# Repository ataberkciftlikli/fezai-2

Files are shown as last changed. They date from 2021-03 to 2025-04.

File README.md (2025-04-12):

# fezai-2
Halley'in Çırakları Rocket Team - Fezai II - Flight Computer - 2021

Main Flight Computer -> Teensy 3.5 Microcontroller
                     -> Adafruit Ultimate GPS
                     -> Xbee Pro S2C
                     -> BMP 280
                     -> MPU6050
                     -> LM2596-ADJ
                     -> IRF540

Second Flight Computer -> Teensy 3.5 Microcontroller
                       -> Adafruit Ultimate GPS
                       -> Xbee Pro S2C
                       -> BMP 180
                       -> MPU9050
                       -> LM2596-ADJ
                       -> IRF540

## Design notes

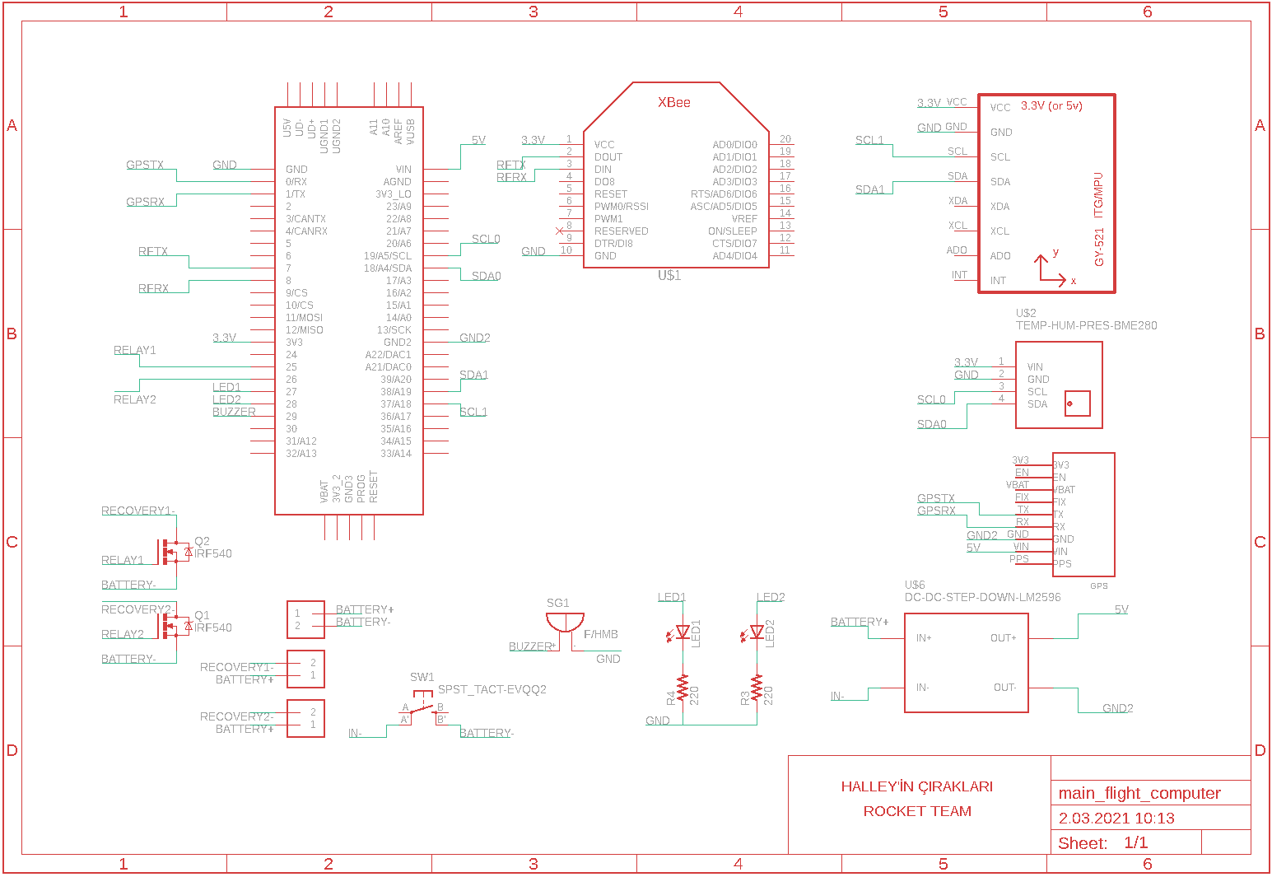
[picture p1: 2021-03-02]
Main Flight Computer/Schematic.png

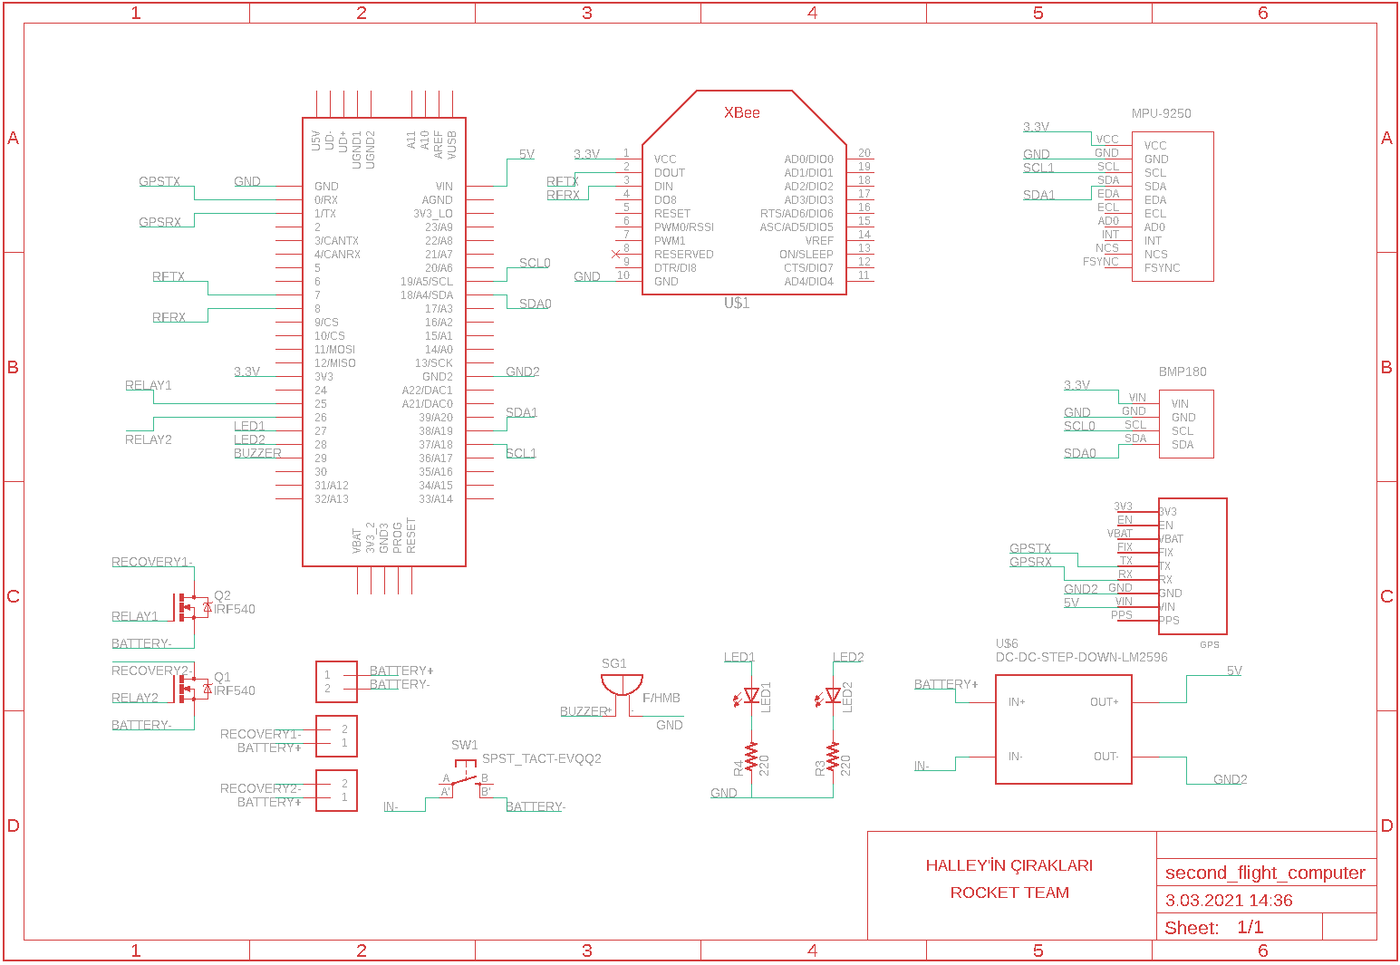
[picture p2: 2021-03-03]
Second Flight Computer/Schematic.png

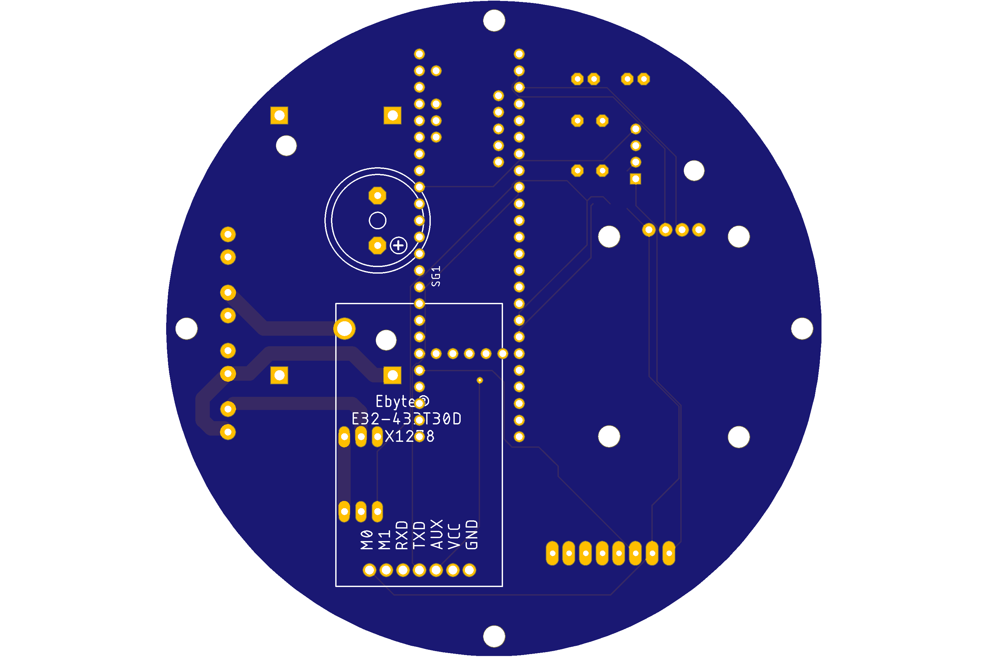
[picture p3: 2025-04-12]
Flight Computer v1.2/main_flight_computer_bottom.png

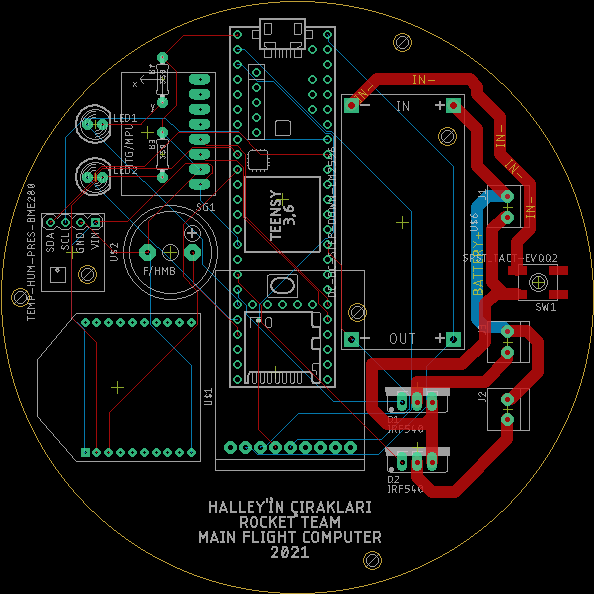
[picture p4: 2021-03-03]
Main Flight Computer/Board.png

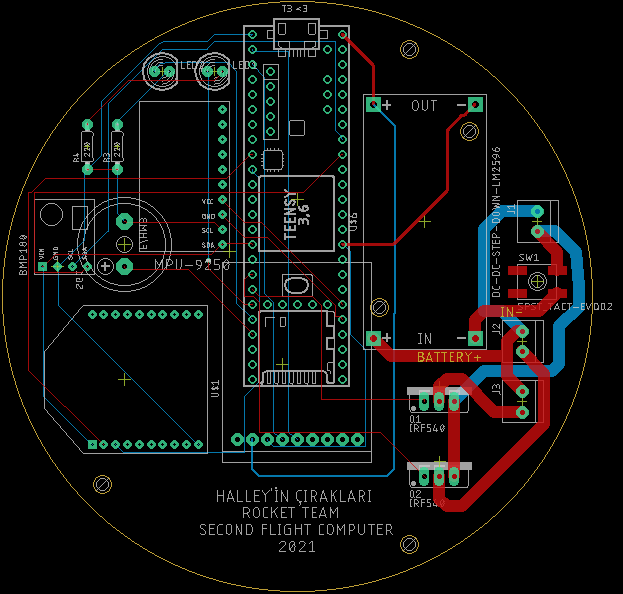
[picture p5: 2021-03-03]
Second Flight Computer/Board.png

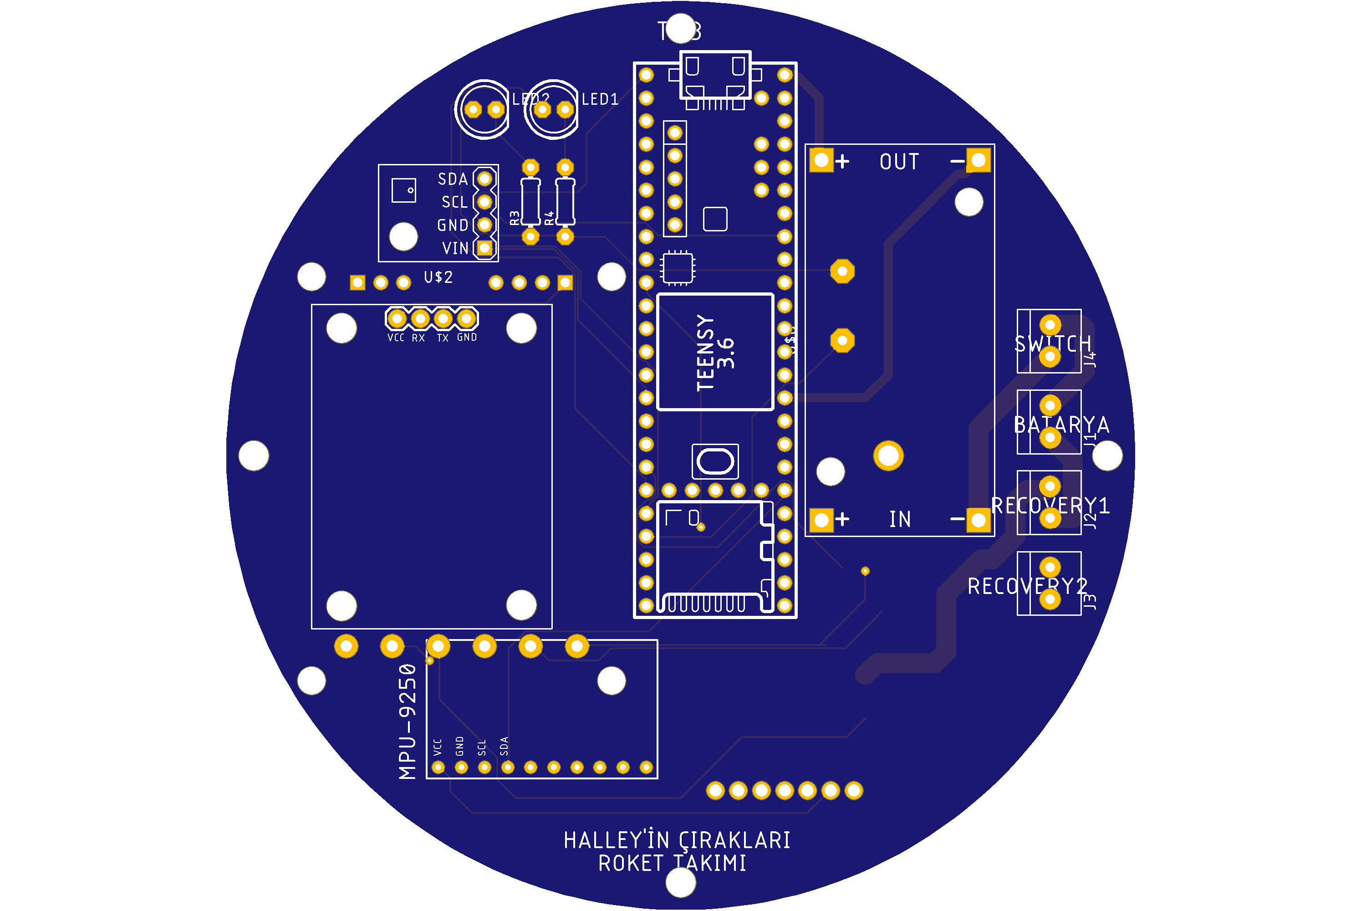
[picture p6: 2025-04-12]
Flight Computer v1.2/secondary_flight_computer_front.png

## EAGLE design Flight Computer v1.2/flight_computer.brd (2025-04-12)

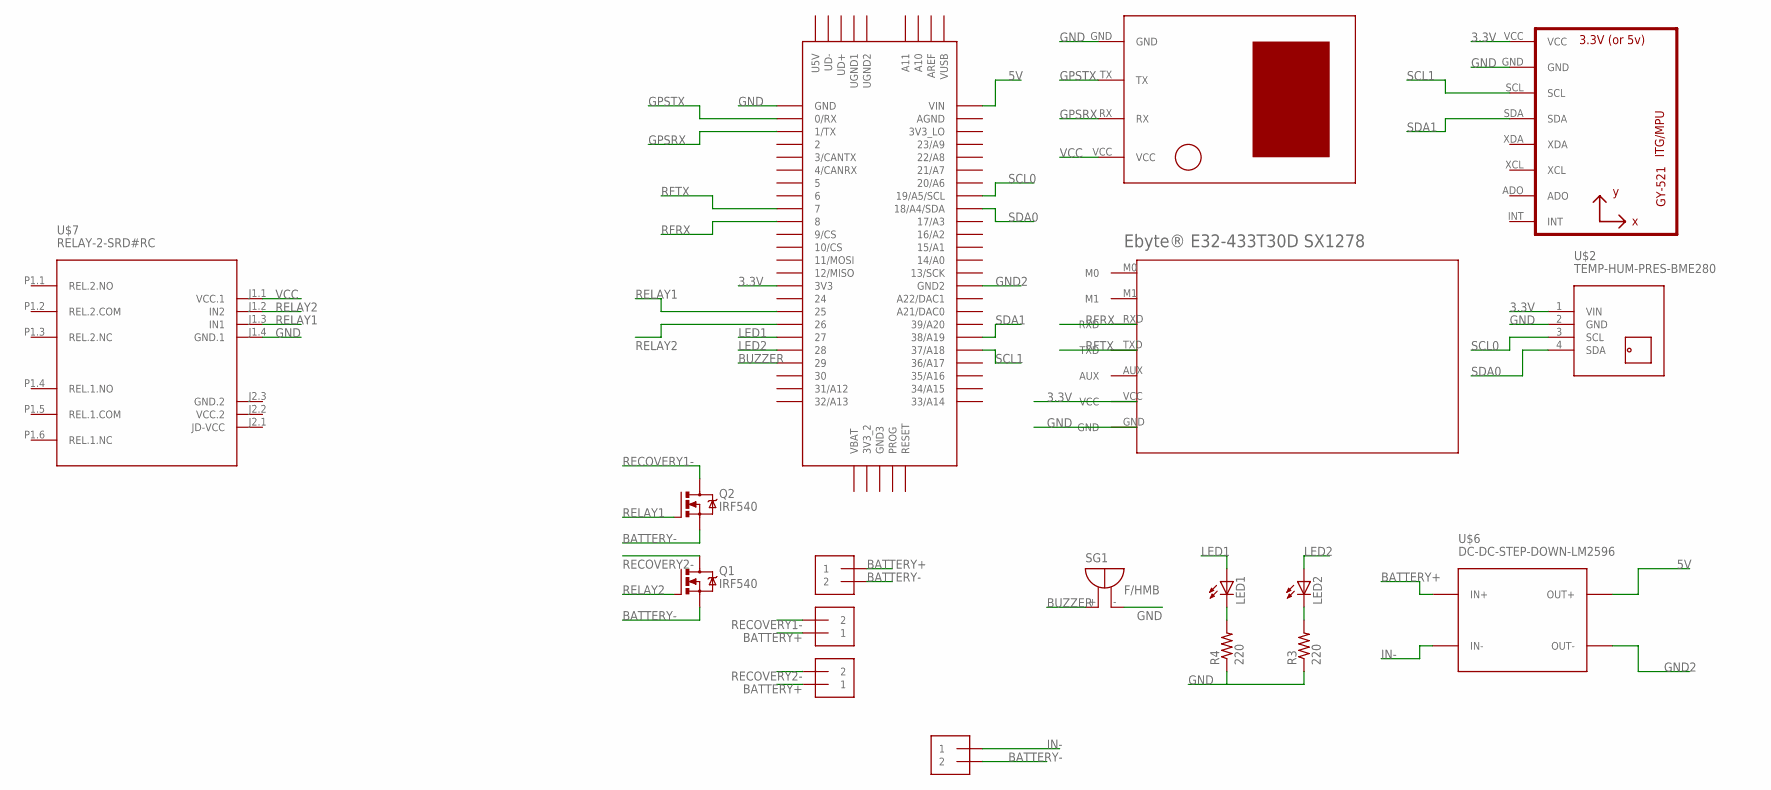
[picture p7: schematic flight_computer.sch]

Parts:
J1, J2, J3, J4: 1X2-3.5MM
LED1, LED2: LED5MM
Q1, Q2: IRF540; TO220BV
R3, R4: 220; 0204/7
SG1: F/HMB
U1: GY-521MPU6050; GY-521
U$1: U-BLOX-NEO6V2
U$2: TEMP-HUM-PRES-BME280
U$3: TEENSY_3.5/3.6
U$4: EBYTE®E32-433T30DSX1278; E32-433T30D
U$6: DC-DC-STEP-DOWN-LM2596
U$7: RELAY-2-SRD#RC

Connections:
3.3V: U1.VCC, U$2.1 (VIN), U$3.3V3, U$4.VCC
5V: U$3.VIN, U$6.OUT+
BATTERY+: J1.1, J2.1, J3.1, U$6.IN+
BATTERY-: J1.2, J4.2, Q1.S, Q2.S
BUZZER: SG1.+, U$3.29
GND: R3.1, R4.1, SG1.-, U1.GND, U$1.GND, U$2.2 (GND), U$3.GND, U$4.GND, U$7.J1.4 (GND.1)
GND2: U$3.GND2, U$6.OUT-
GND.2: U$7.J2.3 (GND.2)
GPSRX: U$1.RX, U$3.1/TX
GPSTX: U$1.TX, U$3.0/RX
IN-: J4.1, U$6.IN-
LED1: LED1.A, U$3.27
LED2: LED2.A, U$3.28
unnamed: LED1.K (C), R4.2
unnamed: LED2.K (C), R3.2
RECOVERY1-: J2.2, Q2.D
RECOVERY2-: J3.2, Q1.D
RELAY1: Q2.G, U$3.25, U$7.J1.3 (IN1)
RELAY2: Q1.G, U$3.26, U$7.J1.2 (IN2)
RFRX: U$3.8, U$4.RXD
RFTX: U$3.7, U$4.TXD
SCL0: U$2.3 (SCL), U$3.19/A5/SCL
SCL1: U1.SCL, U$3.37/A18
SDA0: U$2.4 (SDA), U$3.18/A4/SDA
SDA1: U1.SDA, U$3.38/A19
VCC: U$1.VCC, U$7.J1.1 (VCC.1)
VCC.2: U$7.J2.2 (VCC.2)

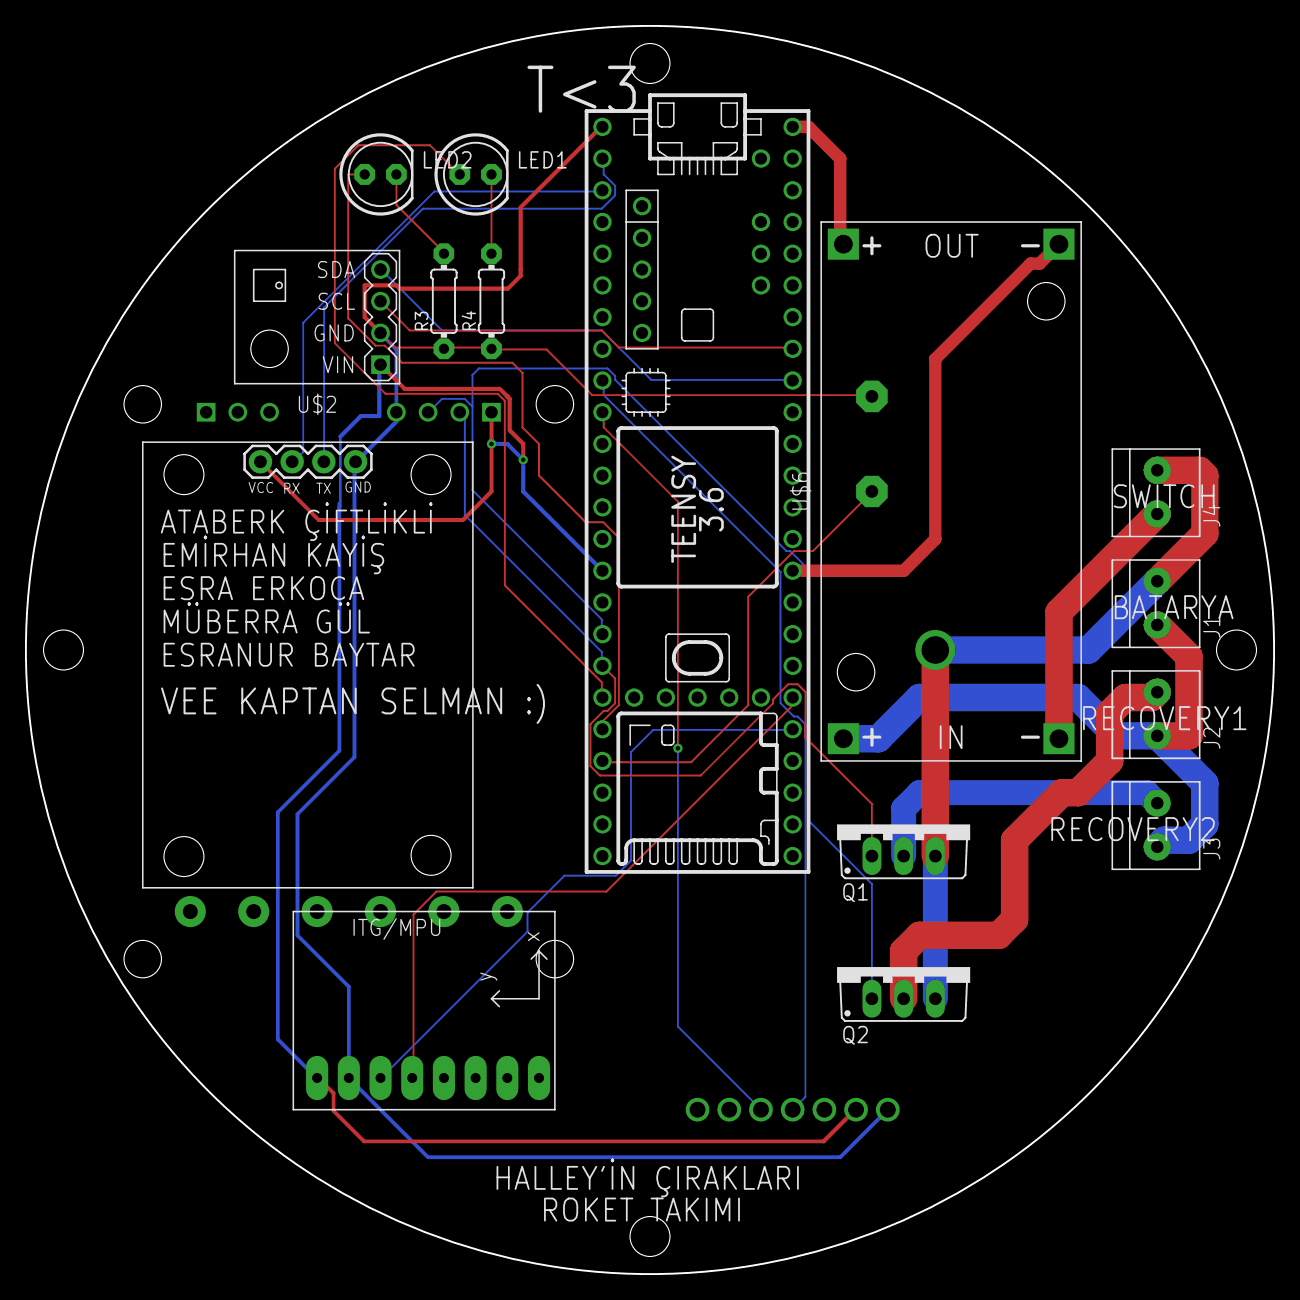
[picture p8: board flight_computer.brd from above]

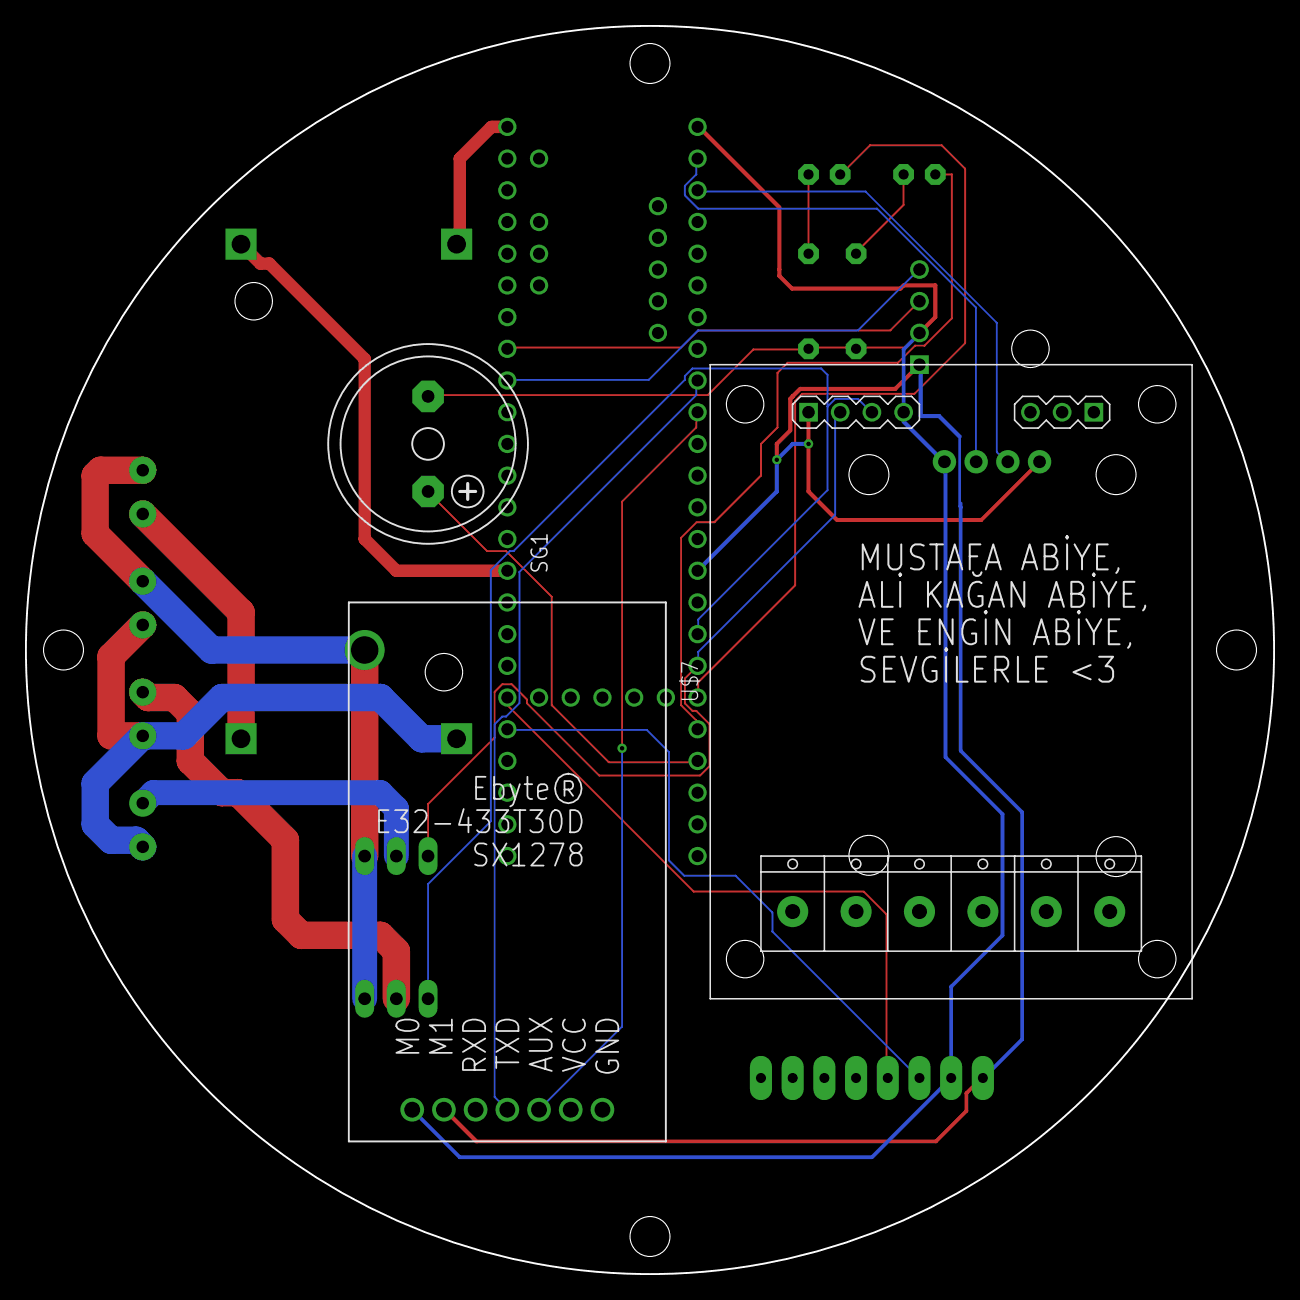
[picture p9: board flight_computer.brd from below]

Board: 2 copper layers, 100.0 x 100.0 mm, 18 parts (3 on the bottom side), 25 nets.

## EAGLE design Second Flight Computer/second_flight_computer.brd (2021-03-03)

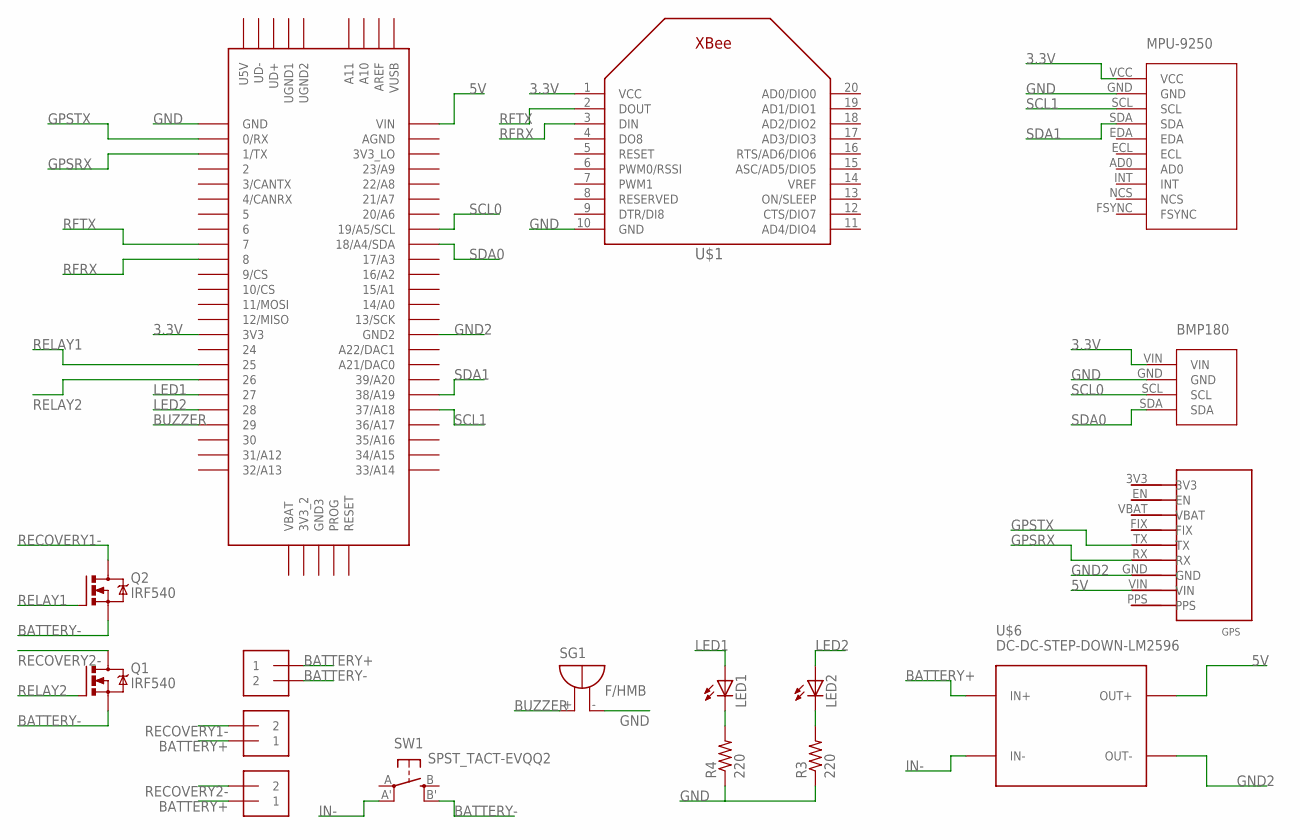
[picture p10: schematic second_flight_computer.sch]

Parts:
BMP1: BMP180
J1, J2, J3: 1X2-3.5MM
LED1, LED2: LED5MM
MPU-1: MPU-9250
Q1, Q2: IRF540; TO220BV
R3, R4: 220; 0204/7
SG1: F/HMB
SW1: SPST_TACT-EVQQ2; EVQ-Q2
U$1: XBEE
U$3: TEENSY_3.5/3.6
U$5: GPS
U$6: DC-DC-STEP-DOWN-LM2596

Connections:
3.3V: BMP1.VIN, MPU-1.VCC, U$1.1 (VCC), U$3.3V3
5V: U$3.VIN, U$5.VIN, U$6.OUT+
BATTERY+: J1.1, J2.1, J3.1, U$6.IN+
BATTERY-: J1.2, Q1.S, Q2.S, SW1.B' (S1)
BUZZER: SG1.+, U$3.29
GND: BMP1.GND, MPU-1.GND, R3.1, R4.1, SG1.-, U$1.10 (GND), U$3.GND
GND2: U$3.GND2, U$5.GND, U$6.OUT-
GPSRX: U$3.1/TX, U$5.RX
GPSTX: U$3.0/RX, U$5.TX
IN-: SW1.A' (P1), U$6.IN-
LED1: LED1.A, U$3.27
LED2: LED2.A, U$3.28
unnamed: LED1.K (C), R4.2
unnamed: LED2.K (C), R3.2
RECOVERY1-: J2.2, Q2.D
RECOVERY2-: J3.2, Q1.D
RELAY1: Q2.G, U$3.25
RELAY2: Q1.G, U$3.26
RFRX: U$1.3 (DIN), U$3.8
RFTX: U$1.2 (DOUT), U$3.7
SCL0: BMP1.SCL, U$3.19/A5/SCL
SCL1: MPU-1.SCL, U$3.37/A18
SDA0: BMP1.SDA, U$3.18/A4/SDA
SDA1: MPU-1.SDA, U$3.38/A19

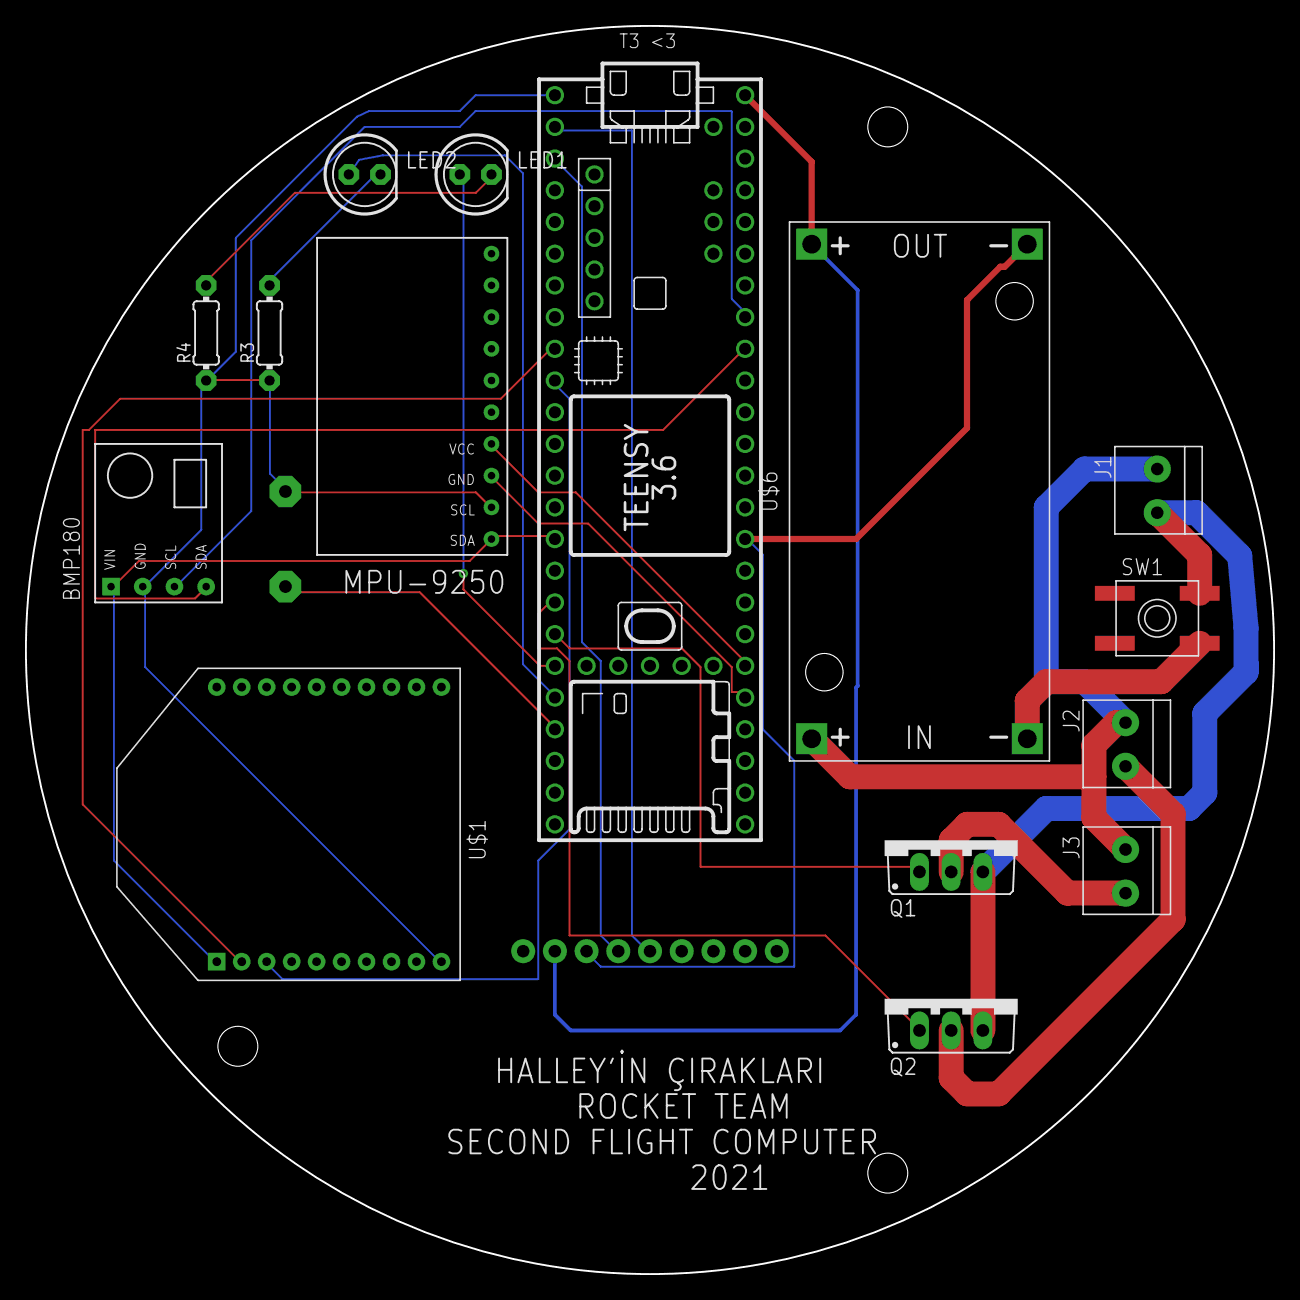
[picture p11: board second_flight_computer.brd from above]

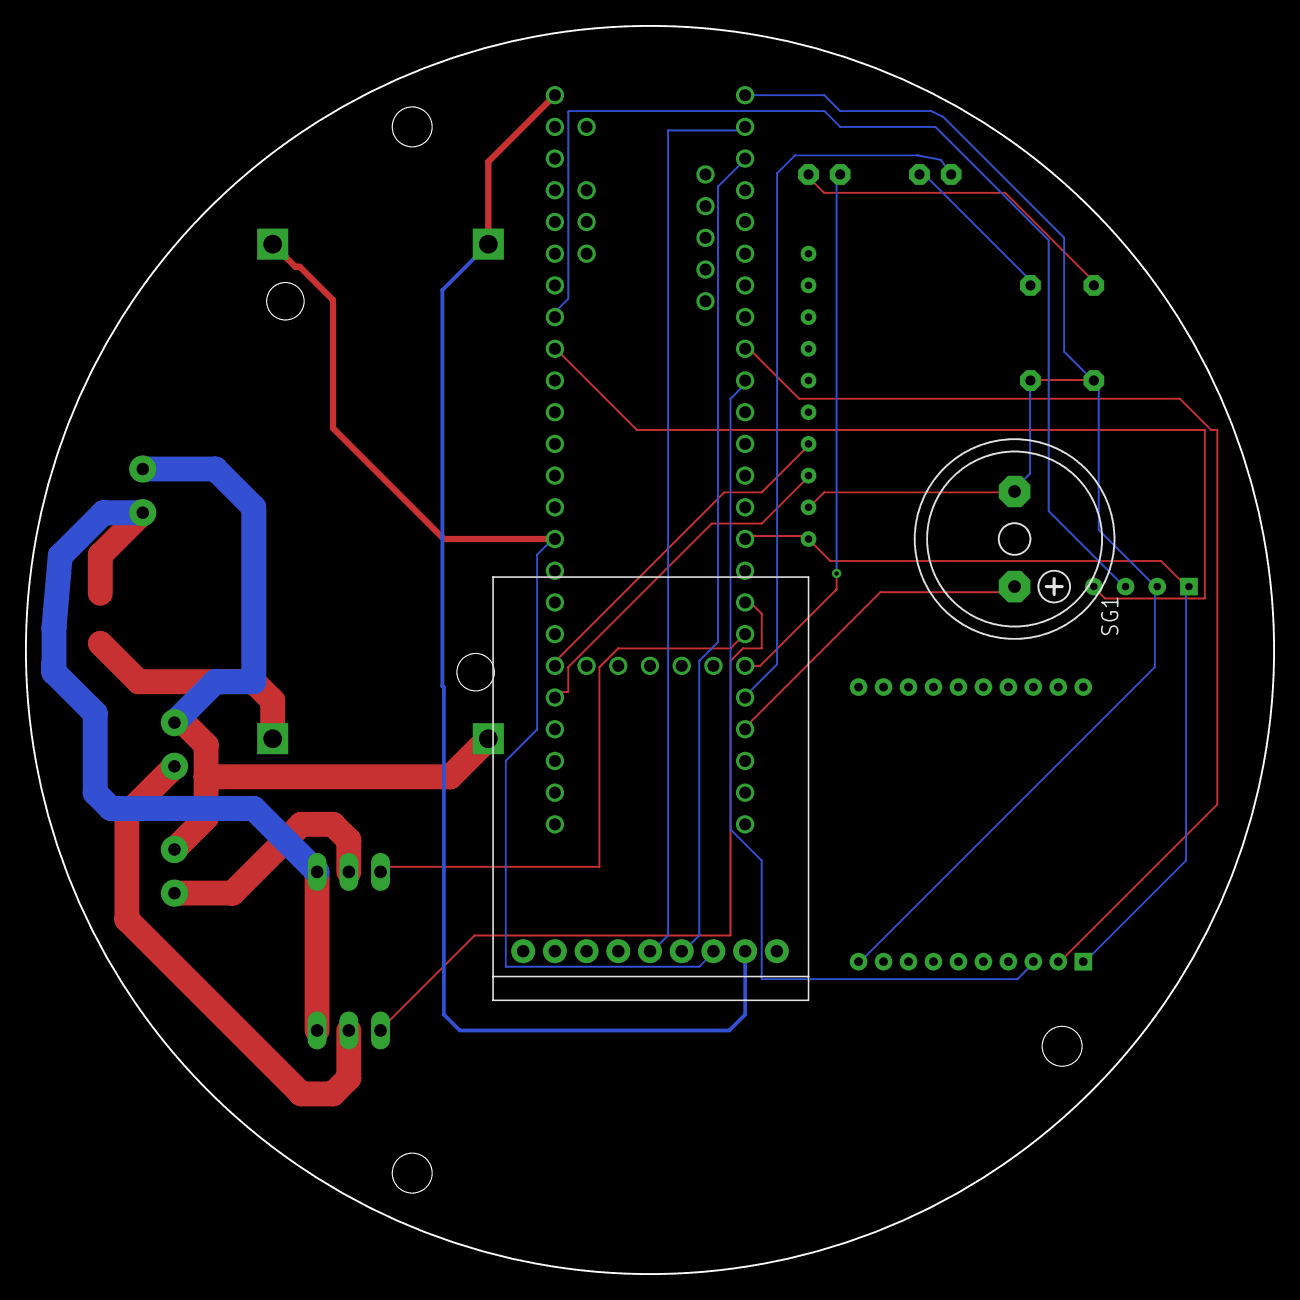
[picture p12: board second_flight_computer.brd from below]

Board: 2 copper layers, 100.0 x 100.0 mm, 17 parts (2 on the bottom side), 24 nets.

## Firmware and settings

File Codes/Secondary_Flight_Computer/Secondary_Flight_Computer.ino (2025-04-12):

#include <SoftwareSerial.h>
#include <Wire.h>
#include <SPI.h>
#include <SFE_BMP180.h> 
#include "MPU9250.h"

MPU9250 mpu;


SoftwareSerial GPS(0, 1); // RX, TX
SFE_BMP180 pressure;  // I2C BMP280

int led_green = 27; // Led 1  -> Green Status Led
int led_red = 28; // Led 2 -> Red Status Led
int buzzer = 29; // Buzzer
int relay_one = 25; // Recovery 1
int relay_two = 26; // Recovery 2

boolean apogee = false;
float altidute;
float altidute_old;
float velocity;

float security_altidute = 1; //DEĞİŞECEK!! STANDART 500
float altidute_secondary = 10; //DEĞİŞECEK!! STANDART 500
float last_altidute = 2; //DEĞİŞECEK!! STANDART 25

double baseline; // baseline pressure

int state = 0;
String state_string;
boolean system_state = false;

String gps_clock = "";    // hhmmss.00
String gps_latitude = "";   // DDMM.MMMM Kuzey/Güney N/S - Enlem
String gps_longitude = "";  // DDMM.MMMM Doğu/Batı E/W - Boylam
String gps_altidute = "";  // metre

void setup() {
  Serial.begin(9600);
  GPS.begin(9600);

  if (pressure.begin())
    Serial.println("BMP180 init success");
  else
  {
    // Oops, something went wrong, this is usually a connection problem,
    // see the comments at the top of this sketch for the proper connections.

    Serial.println("BMP180 init fail (disconnected?)\n\n");
    while(1); // Pause forever.
  }
  

  if (!mpu.setup(0x68)) {  // change to your own address
        while (1) {
            Serial.println("MPU connection failed. Please check your connection with `connection_check` example.");
            delay(5000);
        }
    }

    
   baseline = getPressure();
  
  Serial.print("baseline pressure: ");
  Serial.print(baseline);
  Serial.println(" mb");  


  pinMode(led_green,OUTPUT);
  pinMode(led_red,OUTPUT);
  pinMode(buzzer,OUTPUT);
  //pinMode(relay_one,OUTPUT);
  //pinMode(relay_two,OUTPUT);


  Serial.println("All sensors were calibrated successfully!");
  digitalWrite(led_green,HIGH);
  
  delay(100);
}

void loop() {

 
  altidute = pressure.altitude(getPressure(),baseline);
  mpu.update();

  if(altidute>=security_altidute && state==0) {
    state=1;
    digitalWrite(buzzer,HIGH);
    digitalWrite(led_green,LOW);
    digitalWrite(led_red,HIGH);
    delay(250);
    digitalWrite(buzzer,LOW);
    digitalWrite(led_green,HIGH);
    digitalWrite(led_red,LOW);
  }

  if (state==1 && mpu.getPitch()>35) {
    digitalWrite(relay_one,HIGH);
    digitalWrite(buzzer,HIGH);
    digitalWrite(led_green,LOW);
    digitalWrite(led_red,HIGH);
    delay(1200); //DİRENÇ TELİ SÜRESİ
    digitalWrite(relay_one,LOW);
    digitalWrite(buzzer,LOW);
    digitalWrite(led_green,HIGH);
    digitalWrite(led_red,LOW);
    apogee=true;
    state=2;
}

if(state==2 && altidute<=altidute_secondary) {
    digitalWrite(relay_two,HIGH);
    digitalWrite(buzzer,HIGH);
    digitalWrite(led_green,LOW);
    digitalWrite(led_red,HIGH);
    delay(2000); //LINEER SÜRESİ
    digitalWrite(relay_one,LOW);
    digitalWrite(buzzer,LOW);
    digitalWrite(led_green,HIGH);
    digitalWrite(led_red,LOW);
    state=3;
}

if(state==3 && altidute<=last_altidute && 0<=altidute_old-altidute<=1) {
    state=4;
}


  switch (state) {
  case 0:
    state_string="Yerde"; // Waiting for flight
    break;
  case 1:
    state_string="Uçuş"; // Flight started
    break;
  case 2:
    state_string="Tepe noktasına ulaşıldı! Faydalı yük bıraklıdı. İkinci Paraşüt açıldı."; // Apogee, Payload, Recovery 1 -> Secondary Parachute
    break;
  case 3:
    state_string="Ana paraşüt açıldı!"; // 500 meters, Recovery 2 -> Main Parachute
    break;
  case 4:
    state_string="İniş Tamamlandı!"; // Flight completed
    digitalWrite(led_green,LOW);
    digitalWrite(buzzer,HIGH);
    delay(800);
    digitalWrite(led_green,HIGH);
    digitalWrite(buzzer,LOW);
    delay(500);
    digitalWrite(buzzer,HIGH);
    break;
}
  
  ListenGPS();
  Serial.println("<------ VERİ ------>");
  //Serial.print("Saat:");
  //Serial.println(gps_clock);
  Serial.println("Enlem: 4099.7555");
  //Serial.println(gps_latitude);
  Serial.print("Boylam: 2906.4266");
  //Serial.print("GPS İrtifa:");
  //Serial.println(gps_altidute);
  Serial.println("");
  
    Serial.print("Yaw, Pitch, Roll: ");
    Serial.print(mpu.getYaw(), 2);
    Serial.print(", ");
    Serial.print(mpu.getPitch(), 2);
    Serial.print(", ");
    Serial.println(mpu.getRoll(), 2);
  
  Serial.print("BMP İrtifa: ");
  Serial.println(altidute);
  Serial.print("Rakım (basınç): ");
  Serial.println(baseline);
  Serial.println("");

  Serial.print("Durum: ");
  Serial.println(state_string);

  Serial.print("Sistem Durumu: ");
  Serial.println(system_state);

  Serial.println("");
  
  //delay(1000);



}

void ListenGPS() {

  if ( GPS.find("$GPGGA,") ) {

    gps_clock = GPS.readStringUntil(',');
    gps_latitude = GPS.readStringUntil(',');
    gps_latitude.concat(GPS.readStringUntil(','));
    gps_longitude = GPS.readStringUntil(',');
    gps_longitude.concat(GPS.readStringUntil(','));

    for ( int i = 0; i < 3; i++ ) {
      GPS.readStringUntil(',');
    }

    gps_altidute = GPS.readStringUntil(',');
    gps_altidute.concat(GPS.readStringUntil(','));

    GPS.readStringUntil('\r');
  }
} 

double getPressure()
{
  char status;
  double T,P,p0,a;

  // You must first get a temperature measurement to perform a pressure reading.
  
  // Start a temperature measurement:
  // If request is successful, the number of ms to wait is returned.
  // If request is unsuccessful, 0 is returned.

  status = pressure.startTemperature();
  if (status != 0)
  {
    // Wait for the measurement to complete:

    delay(status);

    // Retrieve the completed temperature measurement:
    // Note that the measurement is stored in the variable T.
    // Use '&T' to provide the address of T to the function.
    // Function returns 1 if successful, 0 if failure.

    status = pressure.getTemperature(T);
    if (status != 0)
    {
      // Start a pressure measurement:
      // The parameter is the oversampling setting, from 0 to 3 (highest res, longest wait).
      // If request is successful, the number of ms to wait is returned.
      // If request is unsuccessful, 0 is returned.

      status = pressure.startPressure(3);
      if (status != 0)
      {
        // Wait for the measurement to complete:
        delay(status);

        // Retrieve the completed pressure measurement:
        // Note that the measurement is stored in the variable P.
        // Use '&P' to provide the address of P.
        // Note also that the function requires the previous temperature measurement (T).
        // (If temperature is stable, you can do one temperature measurement for a number of pressure measurements.)
        // Function returns 1 if successful, 0 if failure.

        status = pressure.getPressure(P,T);
        if (status != 0)
        {
          return(P);
        }
        else Serial.println("error retrieving pressure measurement\n");
      }
      else Serial.println("error starting pressure measurement\n");
    }
    else Serial.println("error retrieving temperature measurement\n");
  }
  else Serial.println("error starting temperature measurement\n");
}

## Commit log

2021-03-02 Main Flight Computer PCB Design
    [main_flight_computer.brd, main_flight_computer.sch]
2021-03-03 Second Flight Computer
    [second_flight_computer.brd, second_flight_computer.sch]
2021-03-03 Second Flight Computer PCB Design Updated
    [second_flight_computer.brd]

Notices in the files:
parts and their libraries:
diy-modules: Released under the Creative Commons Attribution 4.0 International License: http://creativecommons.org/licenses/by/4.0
